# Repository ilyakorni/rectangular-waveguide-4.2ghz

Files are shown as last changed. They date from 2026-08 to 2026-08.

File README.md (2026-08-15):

<p align="center">
  <b>Русский</b> | <a href="README.en.md">English</a> | <a href="README.de.md">Deutsch</a>
</p>

# Прямоугольный волновод на моде $H_{10}$ (4.2 ГГц, С-диапазон)

Данный репозиторий содержит материалы проектирования, аналитического расчета и численного 3D электродинамического моделирования тракта прямоугольного полого волновода с основным типом колебаний $H_{10}$ ($TE_{10}$) на центральную рабочую частоту $f_0 = 4.2\text{ ГГц}$ (С-диапазон).

Проект включает математические расчеты в среде PTC Mathcad, твердотельные параметрические CAD-модели с присоединительным фланцем (SolidWorks / STEP), а также верификационный электромагнитный расчет в CST Studio Suite.

---

## Структура репозитория

```text
rectangular-waveguide-4.2ghz/
├── cad/                  # Твердотельные 3D-модели (SolidWorks SLDPRT, STEP)
├── calculations/         # Аналитические расчеты в PTC Mathcad (.xmcd)
├── docs/images/          # Скриншоты расчетов, 3D-моделей и графиков моделирования
└── simulation/           # Проект электромагнитного анализа CST Studio Suite (.cst)
```

---

## Аналитический расчет

Аналитический расчет волноводного тракта выполнен в PTC Mathcad на основе уравнений Максвелла для электродинамики полых металлических волноводов.

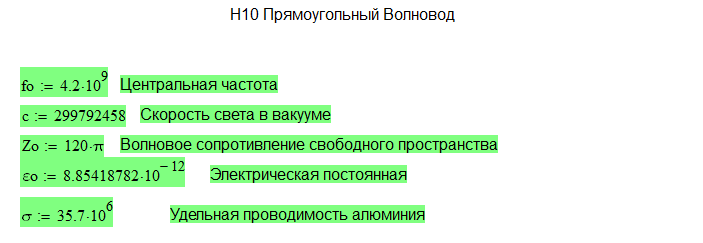
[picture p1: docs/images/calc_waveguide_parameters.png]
Параметры и константы


### 1. Исходные параметры и физические константы
- **Центральная частота**: $f_0 = 4.2\cdot 10^9\text{ Гц}$ ($4.2\text{ ГГц}$)
- **Скорость света в вакууме**: $c \approx 2.998\cdot 10^8\text{ м/с}$
- **Волновое сопротивление свободного пространства**: $Z_0 = 120\pi \approx 376.73\ \Omega$
- **Электрическая постоянная**: $\varepsilon_0 \approx 8.854\cdot 10^{-12}\text{ Ф/м}$
- **Материал стенок**: Алюминиевый сплав с удельной проводимостью $\sigma = 35.7\cdot 10^6\text{ См/м}$

### 2. Геометрические параметры и полоса одномодового режима
Длина волны в свободном пространстве:
$$\lambda_0 = \frac{c}{f_0} = 71.379\text{ мм}$$

Для обеспечения устойчивого распространения основной моды $H_{10}$ и подавления высших паразитных мод $H_{20}$ / $H_{01}$ выбран размер широкой стенки $a$:
- Минимальный размер: $a_{min} = \frac{\lambda_0}{2} = 35.69\text{ мм}$
- Эффективный расчетный размер широкой стенки: $a_{eff} = 53.534\text{ мм}$
- Размер узкой стенки ($b = 0.5 \cdot a_{eff}$): $b = 26.767\text{ мм}$

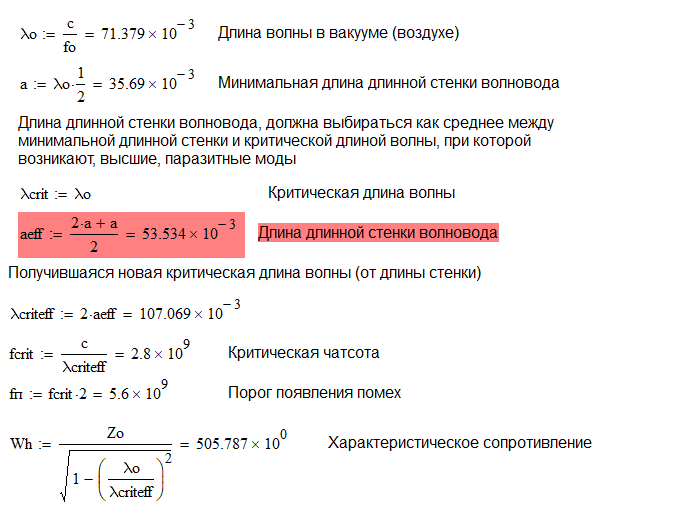
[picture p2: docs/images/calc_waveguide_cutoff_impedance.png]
Критические параметры и сопротивление


### 3. Электродинамические характеристики
- **Критическая длина волны основной моды**: $\lambda_{crit} = 2 \cdot a_{eff} = 107.069\text{ мм}$
- **Критическая частота отсечки ($H_{10}$)**: $f_{crit} = \frac{c}{\lambda_{crit}} = 2.80\text{ ГГц}$
- **Порог возникновения высших мод**: $f_{high} = 2 \cdot f_{crit} = 5.60\text{ ГГц}$
- **Характеристическое волновое сопротивление моды $H_{10}$**:
  $$W_h = \frac{Z_0}{\sqrt{1 - \left(\frac{\lambda_0}{\lambda_{crit}}\right)^2}} = 505.787\ \Omega$$
- **Длина волны в волноводе**:
  $$\lambda_B = \frac{\lambda_0}{\sqrt{1 - \left(\frac{\lambda_0}{\lambda_{crit}}\right)^2}} = 95.765\text{ мм}$$

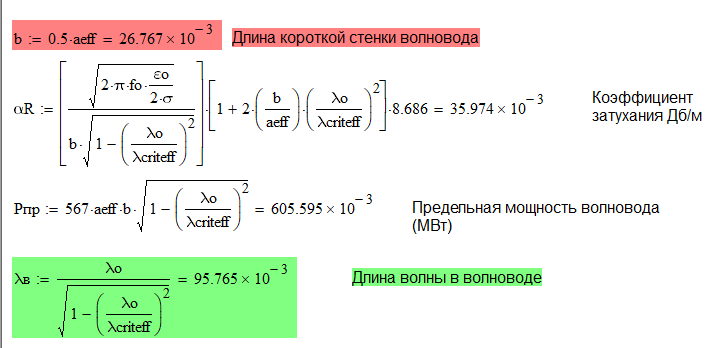
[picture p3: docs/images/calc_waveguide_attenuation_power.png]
Затухание и предельная мощность


- **Коэффициент омического затухания**: $\alpha_R = 35.974\cdot 10^{-3}\text{ дБ/м}$ ($0.036\text{ дБ/м}$)
- **Предельная передаваемая мощность (пробой по воздуху)**: $P_{max} = 605.595\text{ кВт}$

---

## 3D-моделирование

Геометрия волноводной секции смоделирована в SolidWorks и верифицирована в CST Studio Suite. Конструкция включает стандартный прямоугольный волноводный канал внутренним сечением $53.534 \times 26.767\text{ мм}$ и фланцевое соединение с 4 крепежными отверстиями и центрирующей выточкой.

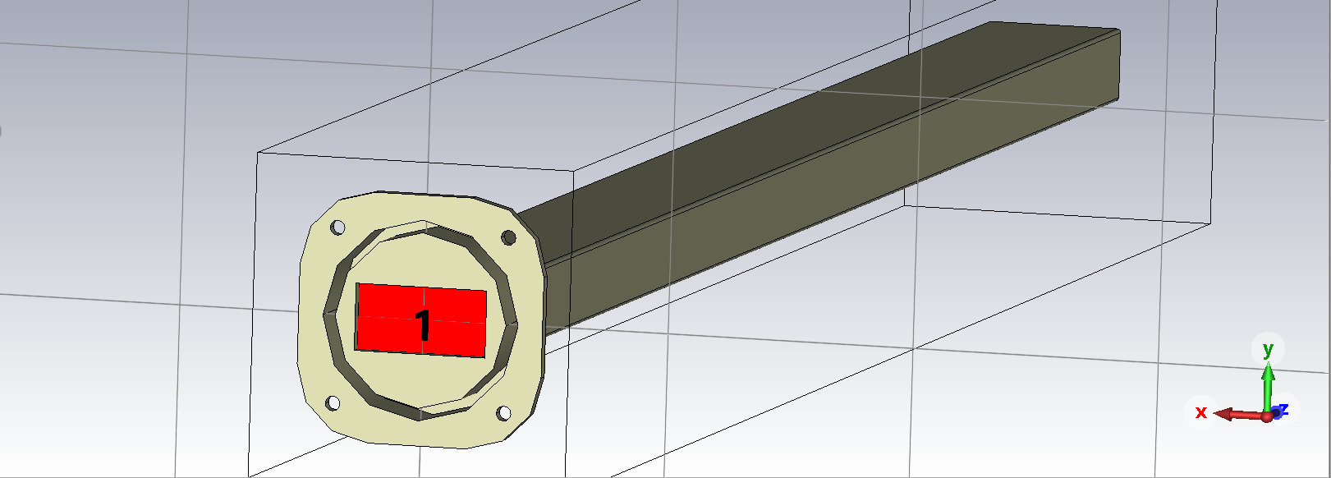
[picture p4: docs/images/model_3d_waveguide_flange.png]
3D-модель волновода в CST Studio Suite


- **Граничные условия**: Открытые граничные условия по направлению распространения, проводящие стенки с учетом поверхностных потерь алюминия.
- **Порты возбуждения**: На торцах волновода установлены волноводные порты (Waveguide Ports) с ориентацией поля доминирующей моды $TE_{10}$.

---

## Результаты моделирования

Численный электромагнитный расчет выполнен в диапазоне частот $3.0\text{--}5.0\text{ ГГц}$.

### 1. Коэффициент стоячей волны по напряжению (КСВН / VSWR)
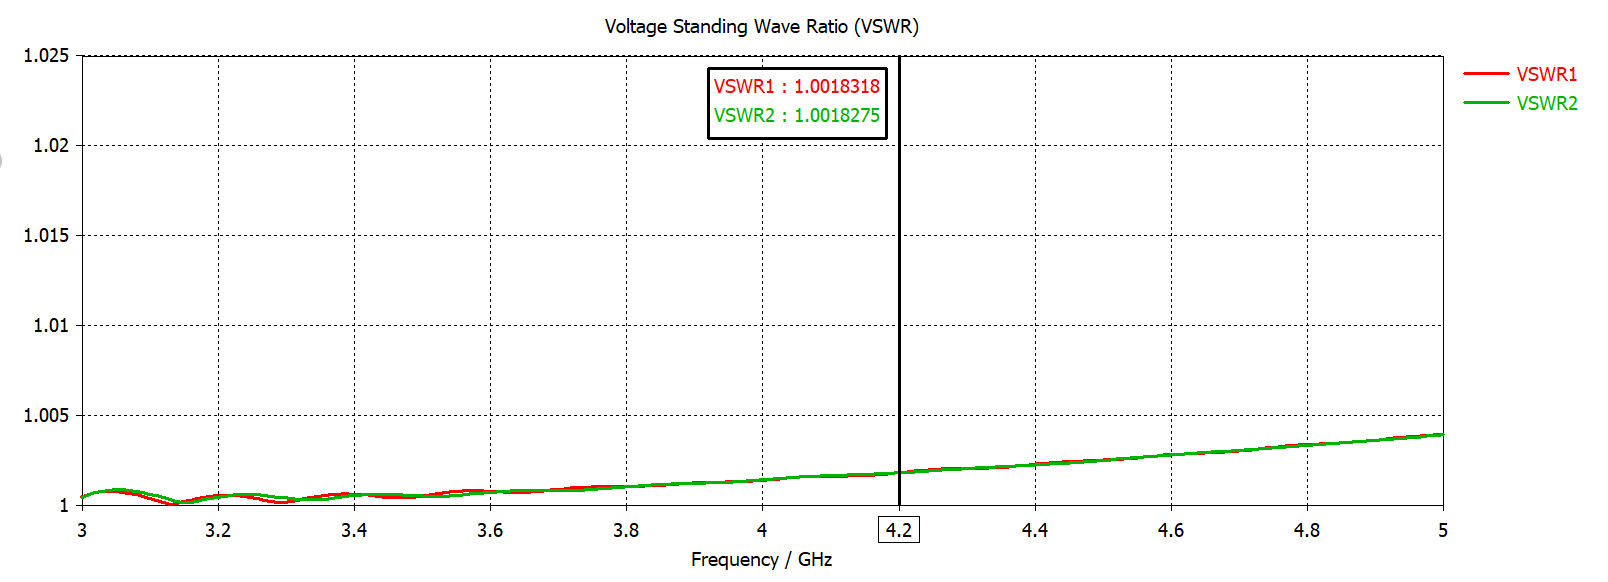
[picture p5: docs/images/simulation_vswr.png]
График КСВН


На центральной рабочей частоте $4.2\text{ ГГц}$ получены следующие значения:
- $\text{VSWR}_1 = 1.00183$
- $\text{VSWR}_2 = 1.00183$

Во всей полосе частот $3.0\text{--}5.0\text{ ГГц}$ уровень КСВН не превышает $1.004$, что подтверждает высокую степень согласования волноводной линии.

### 2. S-параметры (Матрица рассеяния)
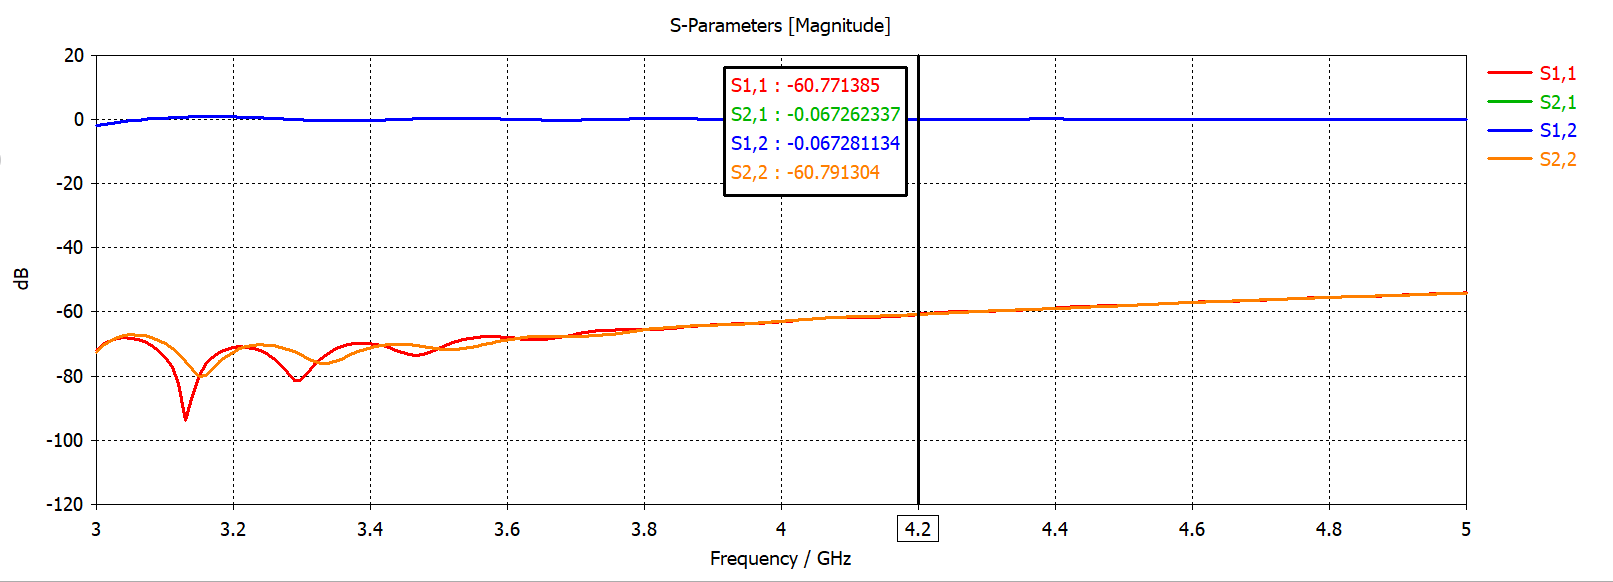
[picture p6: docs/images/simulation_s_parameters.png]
График S-параметров


На центральной частоте $4.2\text{ ГГц}$:
- **Коэффициент отражения ($S_{11}, S_{22}$)**: $-60.77\text{ дБ}$ / $-60.79\text{ дБ}$ (высокий уровень подавления отраженной волны).
- **Коэффициент передачи ($S_{21}, S_{12}$)**: $-0.067\text{ дБ}$ (низкий уровень вносимых потерь на длине волноводного отрезка).

### 3. Z-параметры (Входной и взаимный импеданс)
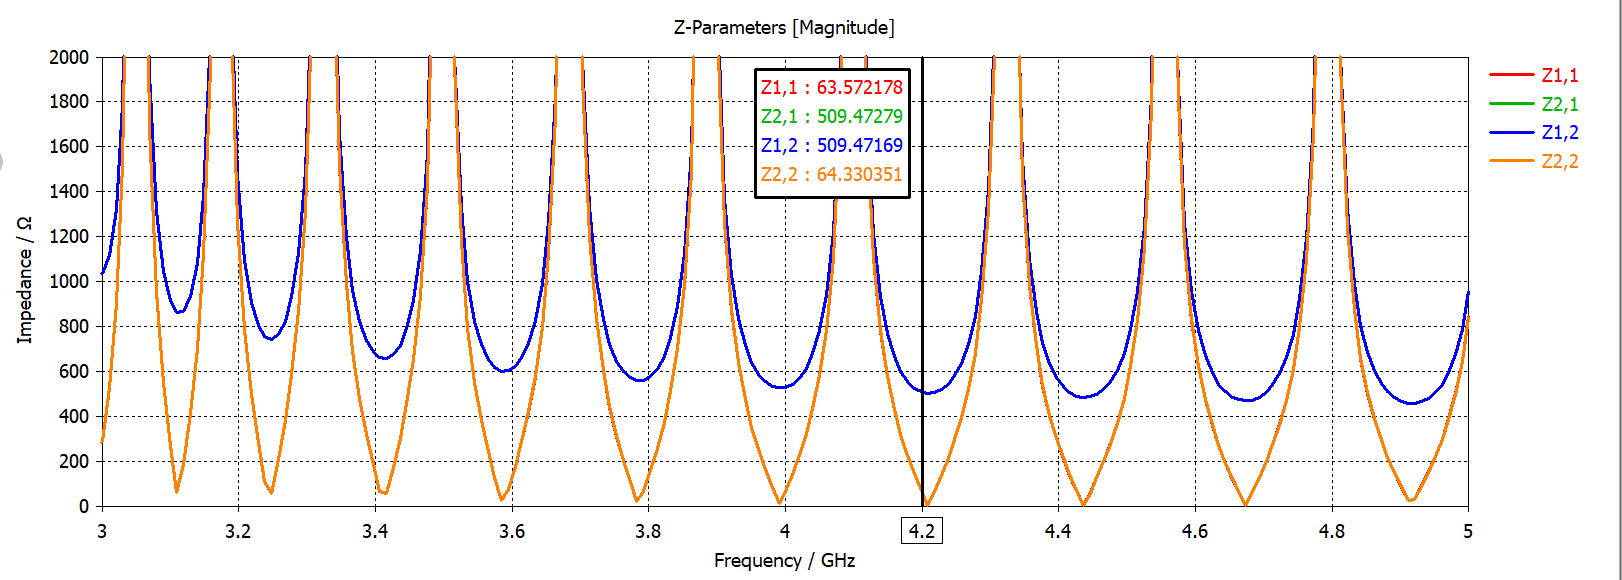
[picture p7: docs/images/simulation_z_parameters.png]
График Z-параметров


На частоте $4.2\text{ ГГц}$:
- **Взаимное сопротивление передачи ($Z_{21}, Z_{12}$)**: $509.47\ \Omega$.

Полученное значение $Z_{21} \approx 509.5\ \Omega$ демонстрирует высокую сходимость с аналитическим волновым сопротивлением $W_h = 505.79\ \Omega$ (расхождение менее $0.73\%$, обусловленное влиянием длины волноводного отрезка и краевыми эффектами портов возбуждения).

---

## Лицензия

Copyright (c) 2026 Илья Корнилов

Этот исходный документ описывает открытое аппаратное обеспечение (Open Hardware) и распространяется под лицензией CERN-OHL-P v2. 
Вы можете распространять и изменять этот исходный документ, а также производить на его основе продукты в соответствии с 
условиями лицензии CERN-OHL-P v2 (https://cern.ch/cern-ohl).

Этот исходный документ распространяется БЕЗ КАКИХ-ЛИБО ЯВНЫХ ИЛИ ПОДРАЗУМЕВАЕМЫХ ГАРАНТИЙ, 
ВКЛЮЧАЯ ГАРАНТИИ ТОВАРНОЙ ПРИГОДНОСТИ, УДОВЛЕТВОРИТЕЛЬНОГО КАЧЕСТВА ИЛИ СООТВЕТСТВИЯ 
КОНКРЕТНЫМ ЦЕЛЯМ. Пожалуйста, ознакомьтесь с условиями CERN-OHL-P v2 для получения подробной информации.

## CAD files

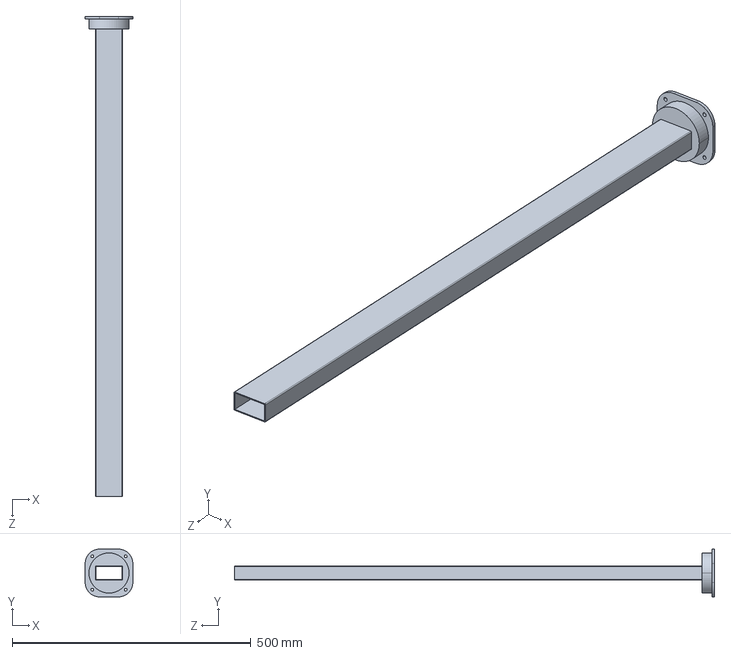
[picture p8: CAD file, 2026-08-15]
cad/rectangular_waveguide_4_2ghz.step
99.9 x 99.9 x 1005.0 mm

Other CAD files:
cad/rectangular_waveguide_4_2ghz.sldprt

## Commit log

2026-08-15 feat: initialize 4.2 GHz H10 rectangular waveguide repository
    - Add SolidWorks (.sldprt) and STEP CAD models for the waveguide section
    - Add Mathcad analytical calculation worksheet (.xmcd)
    - Add CST Studio Suite 3D electromagnetic simulation project (.cst)
    - Set up standardized directory structure and rename assets to snake_case
    - Add project documentation images for calculations, CAD geometry, and simulation plots
    - Add .gitignore and CERN-OHL-P v2 license file
    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
    [rectangular_waveguide_4_2ghz.sldprt, rectangular_waveguide_4_2ghz.step]
2026-08-15 docs: update README.de.md
